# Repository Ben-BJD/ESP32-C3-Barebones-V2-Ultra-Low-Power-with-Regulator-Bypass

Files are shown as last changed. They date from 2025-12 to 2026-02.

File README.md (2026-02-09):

# ESP32-C3 Bare Bones (V2): Ultra-Low Power with Regulator Bypass - KiCAD Source Files

 

Project Available on PCBWay (https://www.pcbway.com/project/shareproject/ESP32_C3_Bare_Bones_V2_Ultra_Low_Power_with_Regulator_Bypass_b012ada1.html)

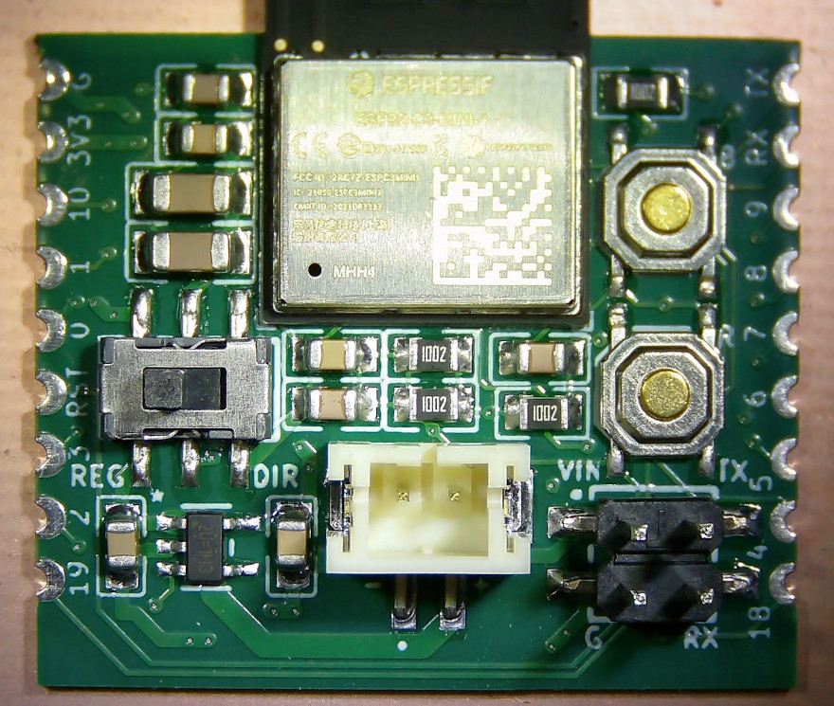
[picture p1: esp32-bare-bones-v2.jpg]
Assembled Board

Fig 1 - Assembled Board
---

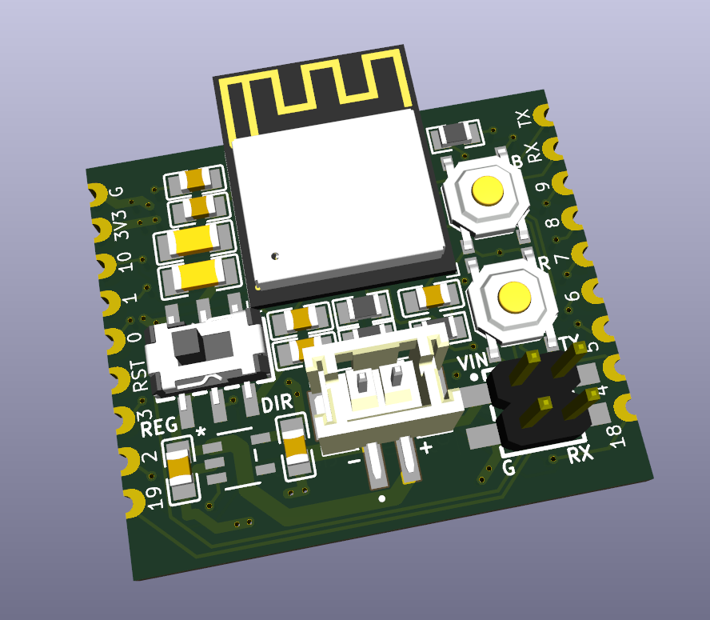
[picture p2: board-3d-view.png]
Kicad 3D View

Fig 2 - 3D view of Board
---

## Overview

This repository contains the KiCAD source files for the **ESP32-C3 Bare Bones Mini (V2)**, a compact, versatile, and ultra-low-power development board.

This project is a significant evolution of the [original "Bare Bones" design](https://github.com/Ben-BJD/esp32-c3-bare-bones), engineered for maximum power efficiency and flexibility. It features a unique dual-mode power system, a 4-layer PCB for improved RF performance, and a compact form factor with castellated edges, making it ideal for both battery-powered IoT prototypes and integration into larger projects.

The design prioritizes hand-assembly by using 0805 and larger SMD components where possible.

## Key Features

*   **Dual Power Modes:** A slide switch selects between a regulated input (REG on the board) for standard LiPo batteries/USB power or a direct-to-MCU bypass for ultra-low-power LiFePO4 operation (DIR on the board).
*   **Ultra-Low Deep Sleep:** Designed to achieve ~5µA deep sleep current in Direct Mode by bypassing the voltage regulator entirely.
*   **Compact & Integratable:** A minimal footprint with castellated holes on the edges allows the board to be soldered directly as a module onto a parent PCB (or solder header pins).
*   **ESP32-C3 Antenna Support:** The layout accommodates both the standard ESP32-C3-MINI-1 with a PCB antenna (overhanging the board) and the ESP32-C3-MINI-1U variant with a U.FL connector for an external antenna.
*   **Onboard Connectors:** Includes a JST-PH connector for batteries and a dedicated 4-pin header for easy programming.
*   **Improved RF Performance:** A 4-layer PCB with dedicated ground and power planes helps reduce noise and improve radio signal integrity.
*   **Hand-Solder Friendly:** Uses larger 0805 components for capacitors and resistors, making it easier to assemble by hand.

## Power System Explained

The board's most unique feature is its slide-switch-controlled dual power system.

### 1. Regulated Mode (for LiPo / 5V USB) [REG]
In this mode, power from the JST connector is routed through the onboard **RT9080 Low-Dropout (LDO) regulator**. This allows you to safely power the board with a standard 3.7V (4.2V max) LiPo battery or a 5V USB power source. This mode is ideal for development or applications where the LDO's quiescent current (typically a few microamps) is acceptable.

### 2. Direct Mode (for LiFePO4 - Ultra-Low Power) [DIR]
This mode **bypasses the LDO regulator entirely**, connecting the battery's positive terminal directly to the ESP32-C3's 3.3V rail. This eliminates the regulator's quiescent current, allowing the board to achieve its lowest possible deep sleep power consumption (~5µA). This mode is specifically designed for 3.2V (nominal) LiFePO4 batteries.

> #### ⚠️ **CRITICAL SAFETY WARNING** ⚠️
> In **Direct Mode**, there is **NO** onboard over-voltage protection. The input voltage must **NEVER exceed 3.6V**, as this will permanently damage the ESP32-C3 chip.
>
> *   Standard LiPo/Li-ion batteries (4.2V max) **CANNOT** be used in this mode.
> *   You **MUST** use a 3.2V LiFePO4 battery. Ideally charged with an external Battery Management System (BMS) that has a high-voltage cutoff at or below 3.6V. You can always test the batteries voltage first. If over 3.6V wait for it to discharge or apply small load with an LED for a few minutes.
> *   If you are unsure, always use Regulated Mode or measure the battery voltage before connecting it in Direct Mode.

## Programming

The board does not have a USB-to-UART converter to save power. You must program it using an external 3.3V FTDI programmer connected to the 4-pin `PROG` header.

Connect your FTDI programmer as follows:
*   GND -> GND
*   VCC -> 3V3 (or 5V if using Regulated Mode)
*   TX -> RX
*   RX -> TX

To enter bootloader mode, hold down the `BOOT` button, press and release the `RESET` button, and then release the `BOOT` button.

---

## Resources

 

Project Available on PCBWay (https://www.pcbway.com/project/shareproject/ESP32_C3_Bare_Bones_V2_Ultra_Low_Power_with_Regulator_Bypass_b012ada1.html)

*   **ESP32-C3-MINI-1 MCU Datasheet:** [PDF Link](https://www.espressif.com/sites/default/files/documentation/esp32-c3-mini-1_datasheet_en.pdf)
*   **ESP32-C3 Hardware Design Guidelines:** [Documentation Link](https://www.espressif.com/sites/default/files/documentation/esp32-c3_hardware_design_guidelines_en.pdf)

## Schematic

[PDF Version](esp32-c3-bare-bones-mini-schematic.pdf)

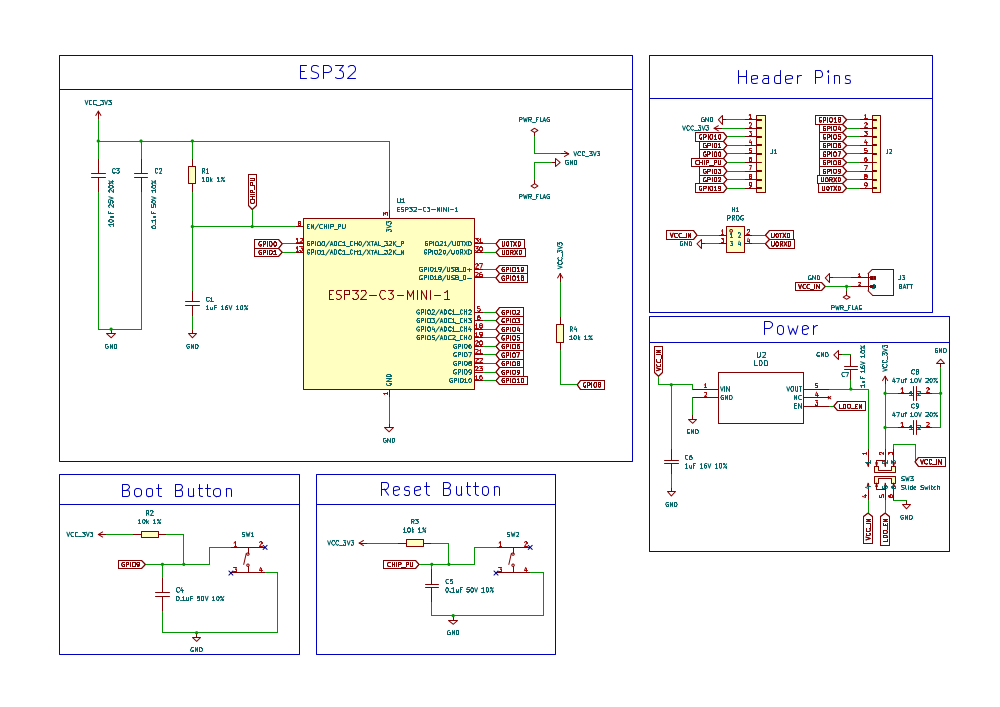
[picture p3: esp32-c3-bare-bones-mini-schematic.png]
Board schematic


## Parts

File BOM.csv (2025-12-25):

Reference | Qty | Value | DNP | Footprint | Product Link
C1,C6,C7 | 3 | 1uF 16V 10% |  | easyeda2kicad:C0805 | https://lcsc.com/product-detail/Multilayer-Ceramic-Capacitors-MLCC-SMD-SMT_SAMSUNG_CL21B105KOFNNNE_1uF-105-10-16V_C24123.html
C2,C4,C5 | 3 | 0.1uF 50V 10% |  | easyeda2kicad:C0805 | https://lcsc.com/product-detail/Multilayer-Ceramic-Capacitors-MLCC-SMD-SMT_C0805B104K500NT_C476766.html
C3 | 1 | 10uF 25V 20% |  | easyeda2kicad:C0805 | https://www.lcsc.com/product-detail/C669099.html
C8,C9 | 2 | 47uf 10V 20% |  | CL31A476MPHNNNE:C1206 | https://lcsc.com/product-detail/Multilayer-Ceramic-Capacitors-MLCC-SMD-SMT_SAMSUNG_CL31A476MPHNNNE_47uF-476-20-10V_C96123.html
H1 | 1 | PROG |  | easyeda2kicad:HDR-SMD_4P-P2.54-V-M-R2-C2-LS7.5 | https://www.lcsc.com/product-detail/C919361.html
J3 | 1 | BATT |  | B2B-PH-SM4-TB:JST_B2B-PH-SM4-TB | https://www.digikey.com.au/en/products/detail/jst-sales-america-inc/B2B-PH-SM4-TB/926831
R1,R2,R3,R4 | 4 | 10k 1% |  | easyeda2kicad:R0805 | https://lcsc.com/product-detail/Chip-Resistor-Surface-Mount-UniOhm_10KR-1002-1_C17414.html
SW1,SW2 | 2 | ~ |  | easyeda2kicad:SW-SMD_4P-L5.1-W5.1-P3.70-LS6.5-TL_H1.5 | https://lcsc.com/product-detail/Tactile-Switches_XKB-Enterprise-TS-1187-B-A-A_C318884.html
SW3 | 1 | Slide Switch |  | G-Switch MS-22D28-G020:SW-SMD_MS-22D28-G020 | https://lcsc.com/product-detail/Toggle-Switches_G-Switch-MS-22D28-G020_C963205.html
U1 | 1 | ESP32-C3-MINI-1 | ESP32-C3-MINI-1-H4X | PCM_Espressif:ESP32-C3-MINI-1 | https://www.lcsc.com/product-detail/C41349510.html?s_z=s_ESP32-C3-MINI-1-H4X
U1 | 1 | ESP32-C3-MINI-1 | ESP32-C3-MINI-1U-N4X | PCM_Espressif:ESP32-C3-MINI-1 | https://www.digikey.com/en/products/detail/espressif-systems/esp32-c3-mini-1u-n4x/27525543
U1 | 1 | Antenna |  | - | https://www.digikey.com.au/en/products/detail/yic/ATIF2458G-3010/21804188
U2 | 1 | LDO |  | RT9080-33GJ5:TSOT-23-5_RIT-M | https://www.digikey.com/en/products/detail/richtek-usa-inc/RT9080-33GJ5/6161634

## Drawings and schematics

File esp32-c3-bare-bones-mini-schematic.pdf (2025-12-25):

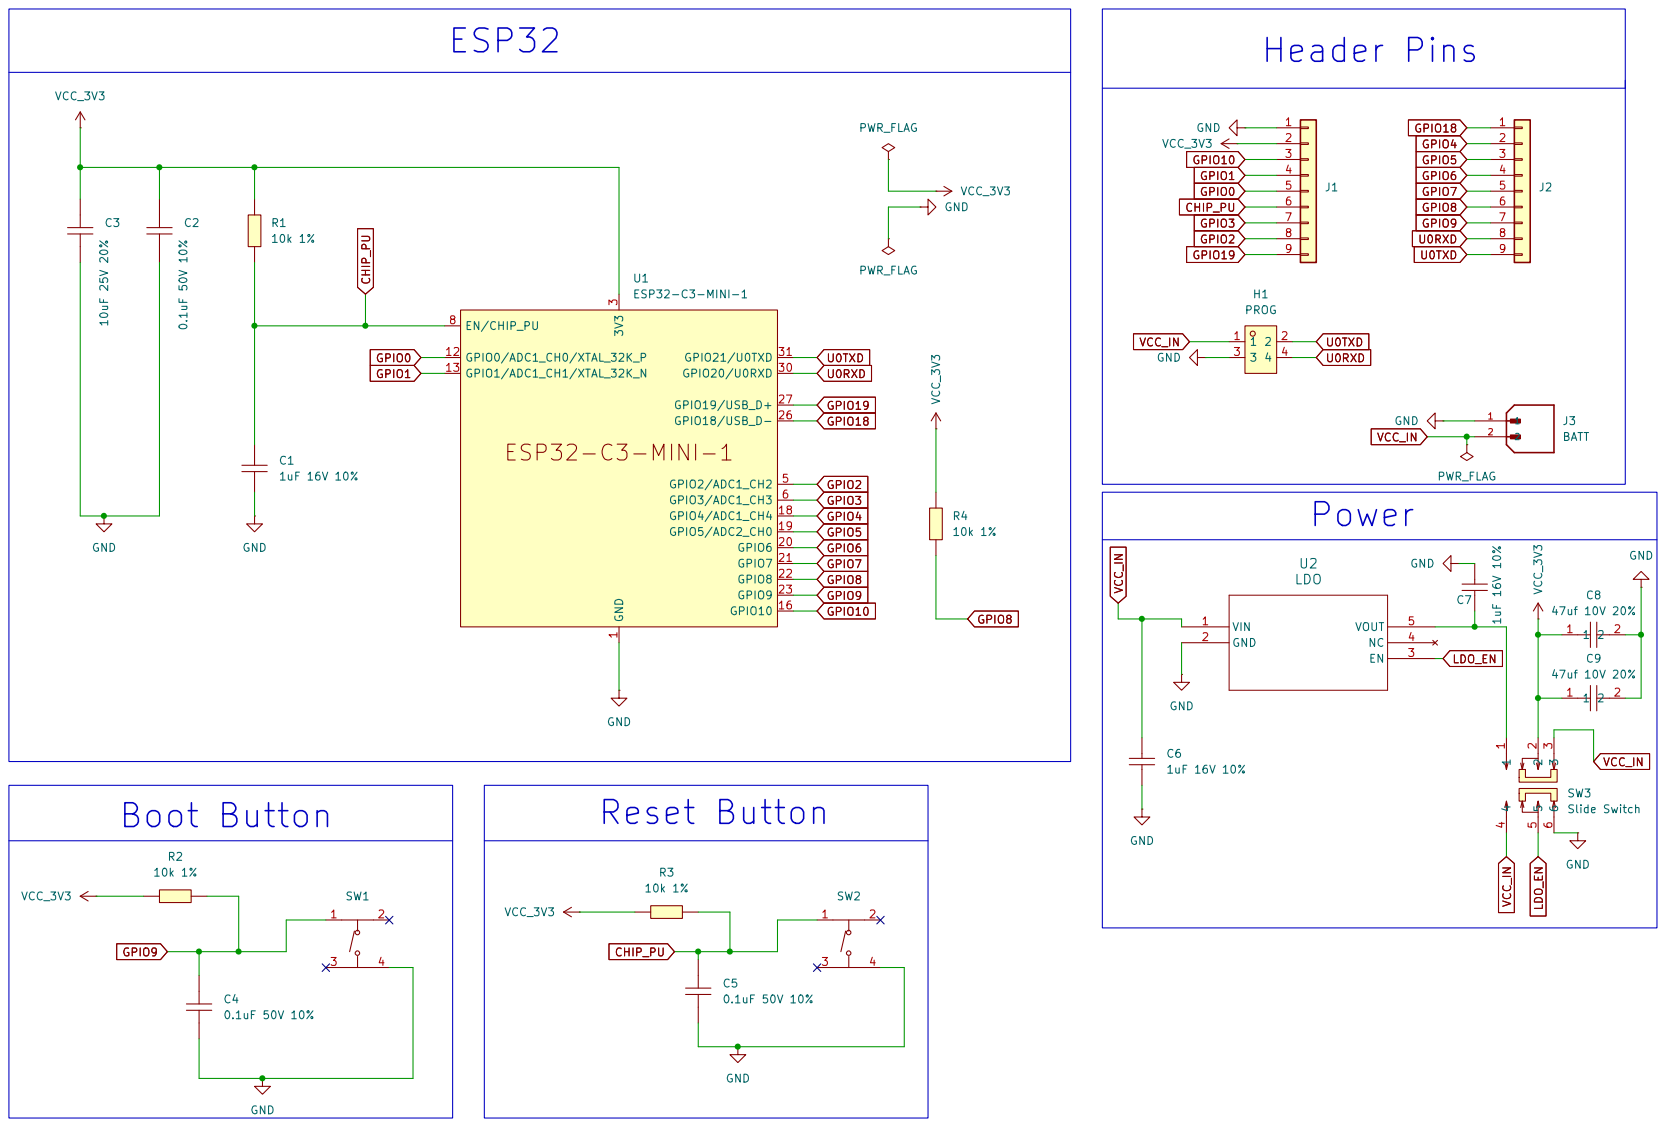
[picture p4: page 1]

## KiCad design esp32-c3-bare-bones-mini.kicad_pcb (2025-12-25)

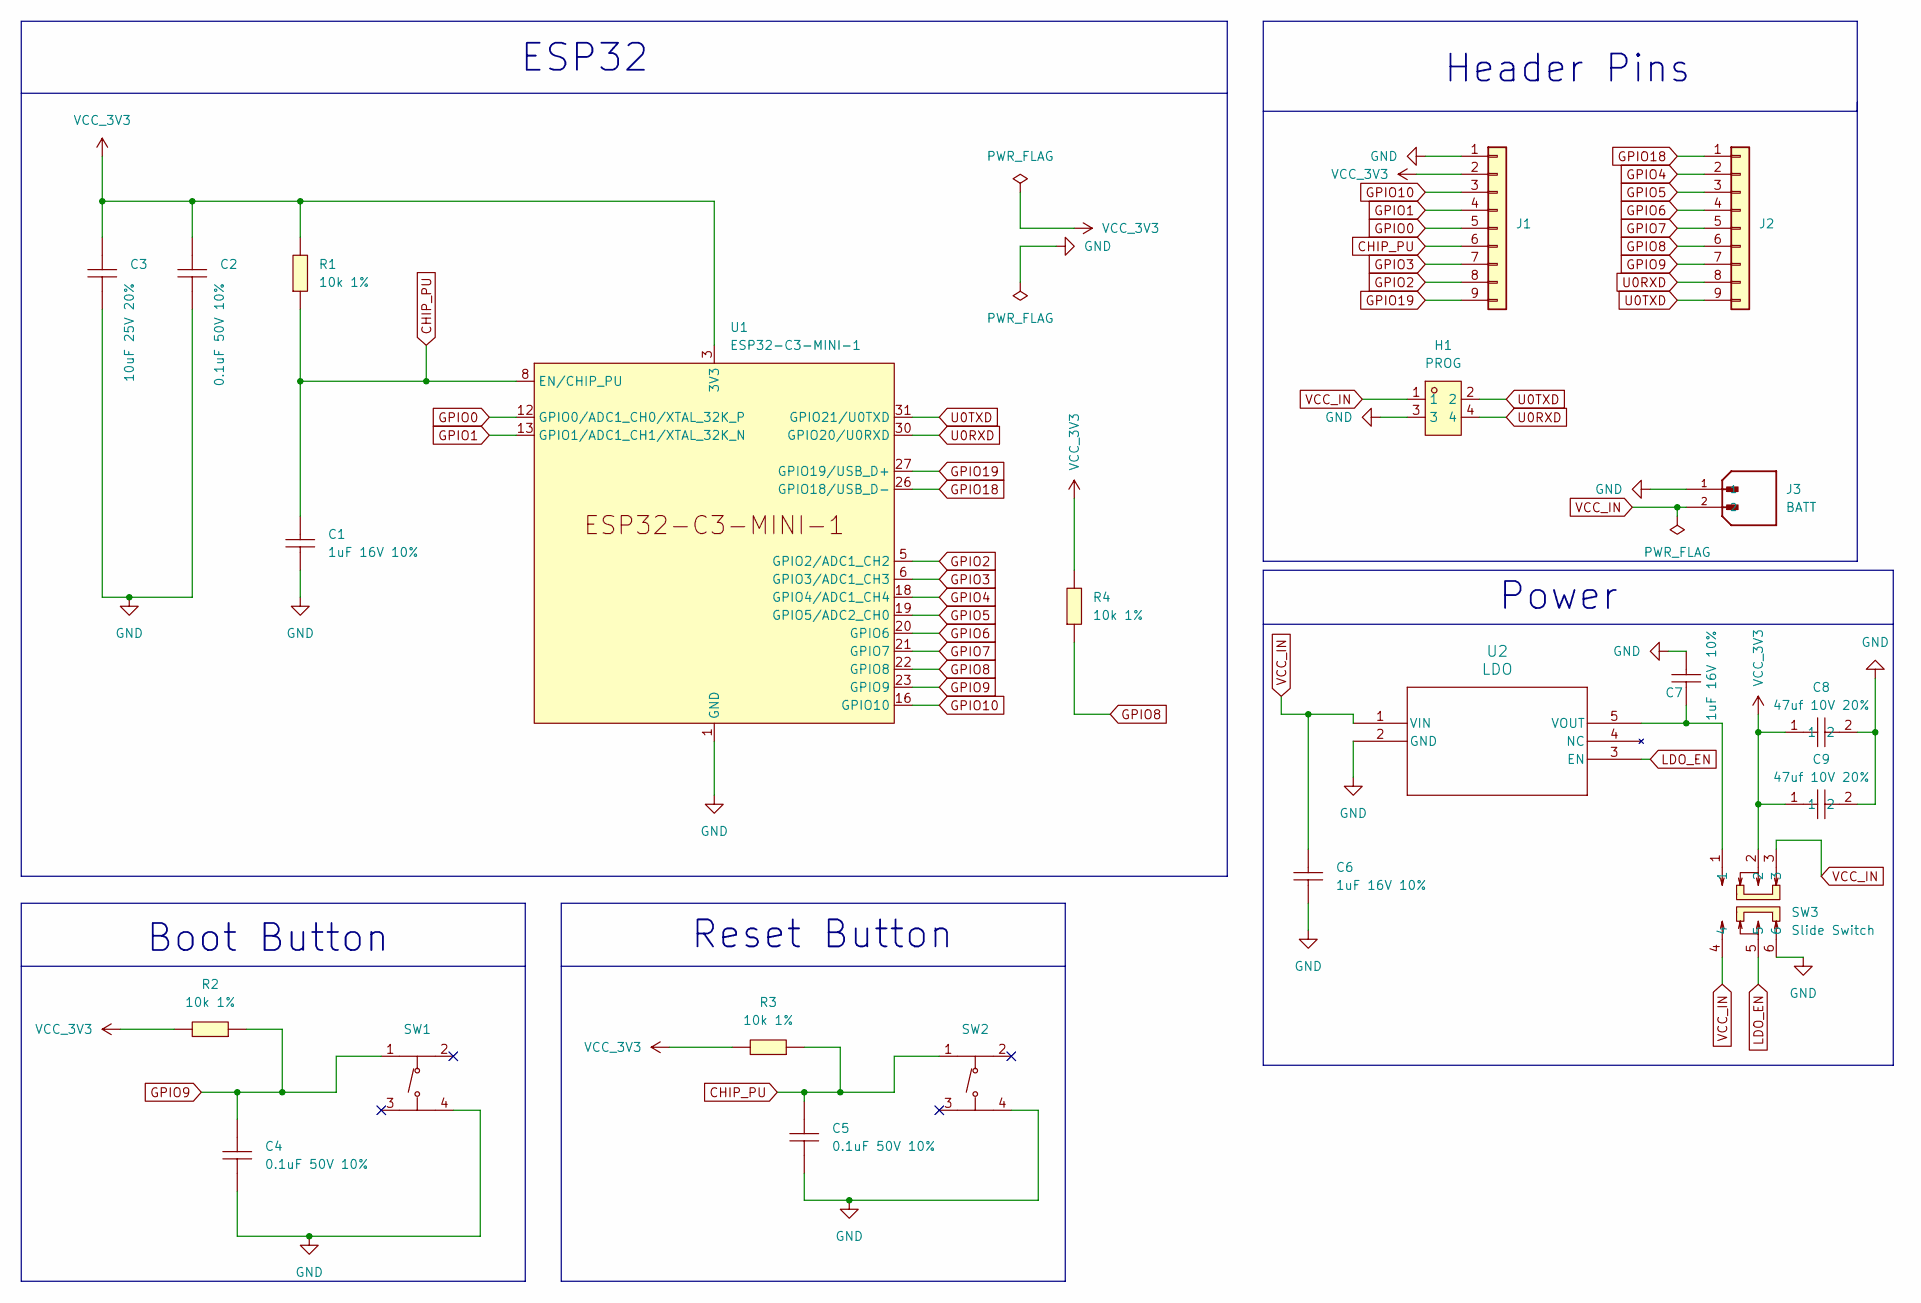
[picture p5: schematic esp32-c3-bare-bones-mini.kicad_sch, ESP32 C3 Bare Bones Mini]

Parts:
C1, C6, C7: 1uF 16V 10%; C0805; LCSC Part C24123
C2, C4, C5: 0.1uF 50V 10%; C0805; LCSC Part C476766
C3: 10uF 25V 20%; C0805; LCSC Part C669099
C8, C9: 47uf 10V 20%; C1206; LCSC Part C96123
H1: PROG; HDR-SMD_4P-P2.54-V-M-R2-C2-LS7.5; LCSC Part C919361
J1, J2: Castellated_9Pin_Row
J3: BATT; JST_B2B-PH-SM4-TB; PARTREV N/A; DigiKey_Part_Number 455-B2B-PH-SM4-TBCT-ND
R1, R2, R3, R4: 10k 1%; R0805; LCSC Part C17414
SW1, SW2: SW-SMD_4P-L5.1-W5.1-P3.70-LS6.5-TL_H1.5; LCSC Part C318884
SW3: Slide Switch; SW-SMD_MS-22D28-G020; LCSC Part C963205
U1: ESP32-C3-MINI-1; Part ESP32-C3-MINI-1-H4X(ANT) | ESP32-C3-MIN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
U2: LDO; TSOT-23-5_RIT-M

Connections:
CHIP_PU: C1.2, C5.2, J1.6, R1.1, R3.1, SW2.1 (A), U1.8 (EN/CHIP_PU); also elsewhere on the board
GND: C1.1, C2.1, C3.1, C4.1, C5.1, C6.1, C7.2, C8.2, C9.2, H1.3, J1.1, J3.1, SW1.4 (D), SW2.4 (D), SW3.6, U1.1 (GND), U1.2 (GND), U1.11 (GND), U1.14 (GND), U1.36 (GND), U1.37 (GND), U1.38 (GND), U1.39 (GND), U1.40 (GND), U1.41 (GND), U1.42 (GND), U1.43 (GND), U1.44 (GND), U1.45 (GND), U1.46 (GND), U1.47 (GND), U1.48 (GND), U1.49 (GND), U1.50 (GND), U1.51 (GND), U1.52 (GND), U1.53 (GND), U2.2 (GND); also elsewhere on the board
GPIO0: J1.5, U1.12 (GPIO0/ADC1_CH0/XTAL_32K_P)
GPIO1: J1.4, U1.13 (GPIO1/ADC1_CH1/XTAL_32K_N)
GPIO2: J1.8, U1.5 (GPIO2/ADC1_CH2)
GPIO3: J1.7, U1.6 (GPIO3/ADC1_CH3)
GPIO4: J2.2, U1.18 (GPIO4/ADC1_CH4)
GPIO5: J2.3, U1.19 (GPIO5/ADC2_CH0)
GPIO6: J2.4, U1.20 (GPIO6)
GPIO7: J2.5, U1.21 (GPIO7)
GPIO8: J2.6, R4.1, U1.22 (GPIO8)
GPIO9: C4.2, J2.7, R2.1, SW1.1 (A), U1.23 (GPIO9); also elsewhere on the board
GPIO10: J1.3, U1.16 (GPIO10)
GPIO18: J2.1, U1.26 (GPIO18/USB_D-)
GPIO19: J1.9, U1.27 (GPIO19/USB_D+)
LDO_EN: SW3.5, U2.3 (EN)
unnamed: C7.1, SW3.1, U2.5 (VOUT)
U0RXD: H1.4, J2.8, U1.30 (GPIO20/U0RXD)
U0TXD: H1.2, J2.9, U1.31 (GPIO21/U0TXD)
VCC_3V3: C2.2, C3.2, C8.1, C9.1, J1.2, R1.2, R2.2, R3.2, R4.2, SW3.2, U1.3 (3V3)
VCC_IN: C6.2, H1.1, J3.2, SW3.3, SW3.4, U2.1 (VIN)

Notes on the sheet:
Reset Button
Header Pins
ESP32
Boot Button
Power

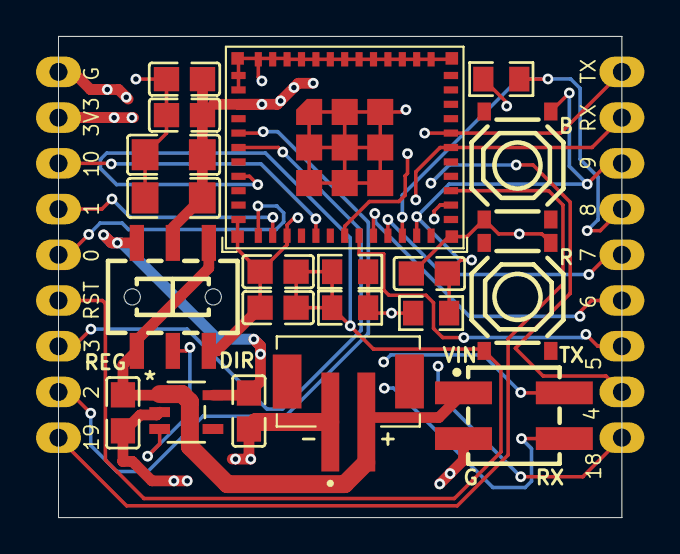
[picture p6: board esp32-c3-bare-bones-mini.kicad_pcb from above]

Board: 4 copper layers, 31.3 x 26.7 mm, 22 parts (0 on the bottom side), 21 nets.

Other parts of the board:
B: SW-SMD_4P-L5.1-W5.1-P3.70-LS6.5-TL_H1.5
R: SW-SMD_4P-L5.1-W5.1-P3.70-LS6.5-TL_H1.5

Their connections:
CHIP_PU: R.1 (A); also elsewhere on the board
GND: B.4 (D), R.4 (D); also elsewhere on the board
GPIO9: B.1 (A); also elsewhere on the board

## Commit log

2025-12-25 Dual-Mode Power
    [BOM.csv, esp32-c3-bare-bones-mini.kicad_pcb, esp32-c3-bare-bones-mini.kicad_sch]
2026-01-26 Add photo of assembled board
2026-01-31 Add PCBWay project
